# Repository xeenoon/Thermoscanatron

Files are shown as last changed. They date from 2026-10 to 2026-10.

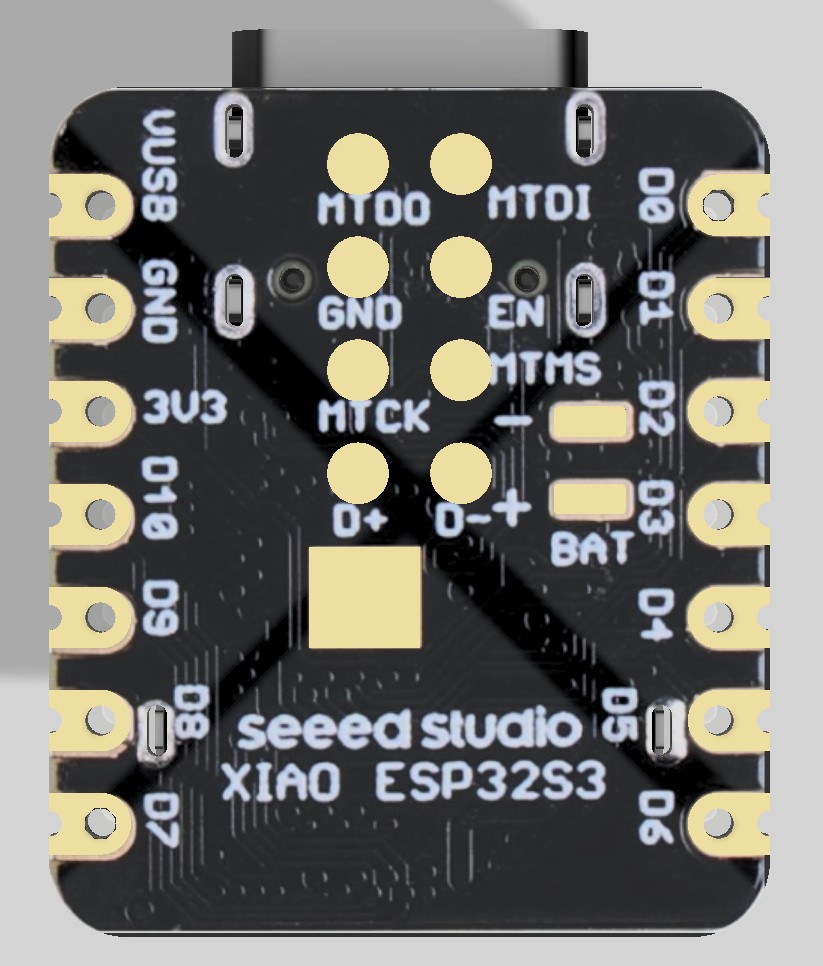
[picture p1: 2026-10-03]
3d/seeed-studio-xiao-esp32s3-3d_model/Bottom View.jpg

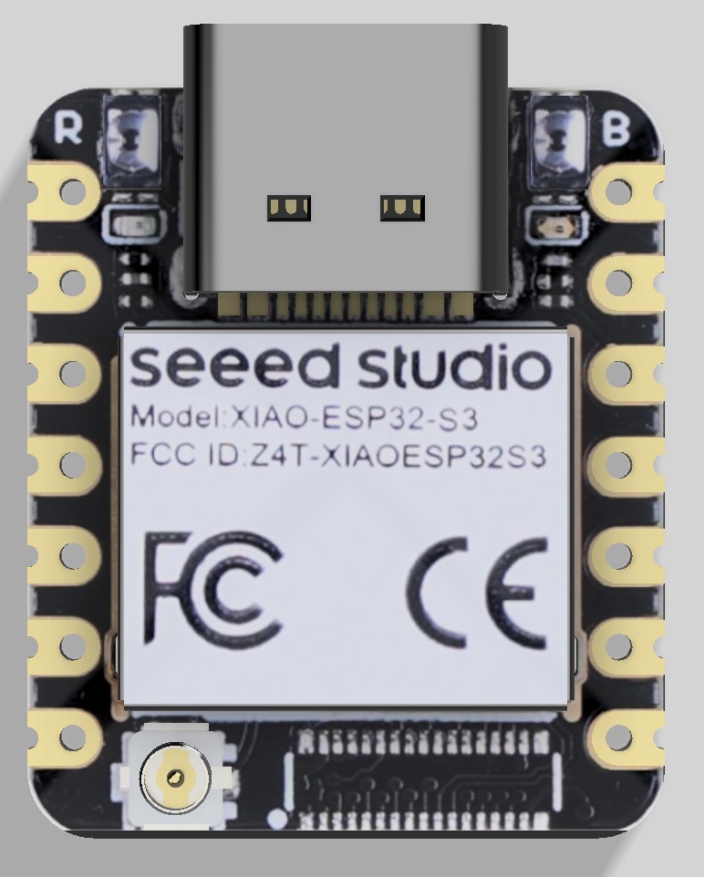
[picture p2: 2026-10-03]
3d/seeed-studio-xiao-esp32s3-3d_model/Top view.jpg

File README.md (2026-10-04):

# Thermoscanatron

## Device components

- MLX90640: $32\times24$ thermal pixels.
- ESP32-S3: factory-calibrated temperature conversion and USB streaming.
- Android app: local ExecuTorch inference, tracking and temperature overlays; the phone also powers the sensor.
- SolidWorks housing: a 3D-printable phone attachment. The revised 100 N simulation gave 1.25 MPa maximum stress and 0.0149 mm displacement.

## Scanner mapping: hand recognition and calibration

HandSegNet uses a MobileNetV3-Small encoder with a U-Net-style decoder and presence head, approximately 1.70 million parameters, at $256\times256$ input resolution.

Our offline labeller combines SegFormer-B2 human parsing with BiRefNet foreground masks and MediaPipe hand landmarks. Landmark-guided cropping removes sleeves; clothing predictions veto false skin regions. These automatically generated masks transfer heavier models' predictions into the compact phone model through supervised pseudo-label training.

The hand estimates the **relative camera pose**. Approximating an open hand as a front-facing plane of area $A_h=130\,\mathrm{cm}^2$, its mask area $a$ gives depth:

```math
Z=f\sqrt{A_h/a},\qquad
P=ZK^{-1}[u,v,1]^T.
```

Here $f$ is focal length in pixels, $K$ is the RGB intrinsic matrix and $(u,v)$ is the hand centroid. For thermal-camera centre $c$ and rotation $R$:

```math
P_T=R^T(P-c),\qquad
R=R_y(\psi)R_x(\theta)R_z(\phi).
```

We fit yaw $\psi$, pitch $\theta$ and roll $\phi$, plus translation, by robust least-squares matching projected hand centroids to thermal warm-blob centroids. The thermal lens uses an equidistant projection: image radius is proportional to ray angle. We then refine pose and lens scale by maximising correlation between projected hand coverage and thermal warmth. Near/far hand motion provides parallax; timestamp alignment compensates sensor delay.

**Training and labelling:** Hand/skin model training totalled **1.84 hours across 13 logged runs**, including validation. The final run used 5,288 training frames, 1,356 validation frames and 2,000 additional negatives. A complete hand-labelling runtime was not retained.

## Solar scanning: recognition, geometry and temperature

PanelNet uses a MobileNetV3-Small encoder and U-Net-style decoder, approximately 1.69 million parameters. The phone uses 192-pixel inputs for fast inference and a 384-pixel recovery model. Outputs include cell masks, gridlines, presence and periodic cell coordinates:

```math
(\sin 2\pi u,\cos 2\pi u,\sin\pi v,\cos\pi v).
```

Column phase repeats every cell; row phase repeats every two rows to encode the panel's alternating diamond pattern. Temporal tracking and gyroscope motion preserve integer cell identities through close-ups.

Our offline labeller combines KLT optical flow, SIFT rematching, gridline/diamond constraints and forward/backward tracking. A hidden Markov model with Viterbi decoding resolves cell numbering across the recording. Its homographies generate dense training targets for the phone network: geometric pseudo-labelling, rather than direct neural teacher/student distillation.

The panel-to-image homography gives its plane pose:

```math
H\sim K[w r_1,\;h r_2,\;t],\qquad n=r_1\times r_2,
```

where $w,h$ are cell dimensions, $r_1,r_2$ are panel axes and $t$ is its origin. A calibrated thermal ray $d$ intersects that plane at:

```math
X=c+\frac{n^T(t-c)}{n^Td}d.
```

Projecting $X-t$ onto the panel axes identifies the cell. Nine rays sample each thermal pixel's footprint; a cell reading accepts only pixels whose entire sampled footprint lies within that cell, excluding boundaries and background.

For accepted thermal pixels $S_i$ in cell $i$ and panel pixels $S_P$:

```math
T_i=\mathrm{median}\{T_p:p\in S_i\},\qquad
\bar T_P=\frac{1}{|S_P|}\sum_{p\in S_P}T_p,\qquad
\Delta T_i=T_i-\bar T_P.
```

We define a **hotspot** as $\Delta T_i>5^\circ\mathrm C$. The implementation flags $|\Delta T_i|>5^\circ\mathrm C$, including cold anomalies. This is our prototype threshold. Readings are apparent surface temperatures with emissivity set to 0.95.

**Training and labelling:** Solar model training totalled **4.23 hours across 22 logged runs**, including validation. One training stage used 8,695 panel frames plus 1,291 negatives. Solar labelling totalled **4.56 logged hours across 74 completed runs on 3–4 October**. These cumulative development totals exclude unlogged work; interrupted labelling runs are additional.

## Demo result

The suspect panel measured 19 V, 4 V below its 23 V baseline; the healthy panel measured 23.7 V, 0.7 V above baseline. Together with the observed hotspots, the voltage deficit supports identifying the demo panel as faulty.

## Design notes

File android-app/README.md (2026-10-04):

# Android apps

Two native Android apps connect on-device computer vision to the USB thermal sensor:

| Module | Application ID | Purpose |
| --- | --- | --- |
| `app/` | `com.euhack.hello` | Hand/skin segmentation, camera calibration and fused thermal viewing |
| `solar/` | `com.euhack.solar` | Solar-cell tracking, temperature mapping and anomaly overlays |

## Setup

Install JDK 17 and the Android SDK. From the repository root, enter this directory and set the paths for your machine:

```bash
cd android-app
export ANDROID_HOME="$HOME/Android/Sdk"
export PATH="$ANDROID_HOME/emulator:$ANDROID_HOME/platform-tools:$PATH"
export JAVA_HOME=/usr/lib/jvm/java-17-openjdk
```

## Run the hand app on a phone

Enable USB debugging and connect the phone, then build and install:

```bash
./gradlew :app:assembleDebug
adb -d install -r app/build/outputs/apk/debug/app-debug.apk
adb -d shell am start -n com.euhack.hello/.DemoActivity
```

The hand app runs live hand/skin segmentation. Its **Options** menu provides:

- **Record camera + thermal**: a silent ≤1080p video to `files/videos/hand_<time>.mp4` (see the [ML workflow](../ML/README.md)) plus a
  session in `files/sessions/<time>/` with every analysed frame (crop, mask, timestamps) and every thermal packet on
  the same clock (`SessionRecorder.kt`). `ML/src/segkit/thermal_calib.py` fits a calibration from a session.
- **Dump NO-HAND frames**: diagnostics to `files/diagnostics/session_<time>/` (see `NoHandLogger.kt`).
- **Stream thermal input**: shows only the MLX90640 thermal image (°C range, max, sensor temperature).
- **Calibrate thermal ↔ camera**: follow the guided near, far, upper-left and lower-left hand positions.
  Keep the open hand visible to both cameras. The result reports yaw, pitch and roll in degrees, translation
  in centimetres and approximate uncertainty. **Use it** saves the result to `files/thermal_calib.json`.
- **Fused thermal view** (after calibrating): displays the cameras' overlapping field of view, with the rest
  black. Visible-image edges guide the enlarged thermal overlay to help associate readings with objects.
  The sensor still measures only 32 × 24 thermal pixels. The status line shows the hand's median temperature
  and the colour scale.

## Thermal camera over USB OTG

Plug the QT Py running the [firmware](../firmware/README.md) into the phone using USB-C or an OTG adapter.
The phone powers the board and reads its calibrated `THM2` stream. Grant Android's USB-access prompt when
connecting the board. Plugging it in can also offer to open the app.

The attachment occupies the phone's USB port. Use wireless debugging (`adb pair` and `adb connect`) during
hardware development.

## Camera calibration

The [Kotlin solver](app/src/main/java/com/euhack/hello/ThermalCalibration.kt) corresponds to the
[Python calibration pipeline](../ML/src/segkit/thermal_calib.py). It fits camera rotation, translation,
thermal lens scale and readout mirroring, subject to physical mounting constraints.

1. **Timing:** estimate thermal latency from the correlation between visible hand area and thermal warm area.
   If the capture cannot establish latency, use the recorded default of 225 ms.
2. **Pose:** estimate hand depth from mask area, assuming an open hand of approximately 130 cm². Match the
   resulting 3D hand centroids to thermal centroids using robust Levenberg–Marquardt and multiple starting poses.
3. **Refinement:** use Nelder–Mead to maximise correlation between predicted hand coverage and thermal warmth,
   refining pose and lens scale.

Follow the guided near/far and corner positions. Depth variation supplies the parallax needed to distinguish
translation from rotation. The app also uses tighter offset constraints for a sensor attached to the phone.

```bash
./gradlew :app:testDebugUnitTest
```

The tests cover synthetic mountings, including 30° yaw, 45° roll and a 20 cm offset. Recorded-session comparisons
require the corresponding local calibration data.

## Solar Cells app

The second app (`com.euhack.solar`, launcher **Solar Cells**) shares the hand app's USB thermal-stream and
calibration code. Build, test and install it with:

```bash
./gradlew :solar:assembleDebug :solar:testDebugUnitTest
adb -d install -r solar/build/outputs/apk/debug/solar-debug.apk
```

Start with a panel corner visible in the guide box, then move closer. The tracker carries the row and column
identities between frames.

A small model (`assets/panelseg_small.pte`, 192 px) runs on every camera frame; the larger model (`panelseg.pte`,
384 px) runs on its own thread and corrects it. Between frames, and through motion blur, the grid follows the
gyroscope. With the thermal camera connected and a saved or bundled calibration, the app displays per-cell
temperatures and flags differences greater than 5 °C from the panel mean. These flags include both hotspots
and cold anomalies.

**Rec** saves model inputs to `files/panel_debug/<time>/` for replay with `segkit-panel-track --crops`.
See the [ML workflow](../ML/README.md#per-cell-temperatures). Models are trained with `segkit-panel-train`.

## Run in an emulator

Use the emulator for the hand app's camera/UI workflow; USB thermal hardware requires a physical phone.
Run these commands after the setup above:

```bash
emulator -list-avds
emulator -avd igcap &
adb -e wait-for-device
while [ "$(adb -e shell getprop sys.boot_completed | tr -d '\r')" != "1" ]; do sleep 1; done

./gradlew :app:assembleDebug
adb -e install -r app/build/outputs/apk/debug/app-debug.apk
adb -e shell am start -n com.euhack.hello/.DemoActivity
```

Replace `igcap` with an AVD shown by `emulator -list-avds`.

## Hand inference performance diagnostics

Normal launches run only the small model with four native threads. The larger model, its input buffer, and its
executor are not created. This avoids background inference blocking tracking and resetting the thread pool.
The larger model remains bundled for optional ADB comparisons. `-S` restarts the process so the native thread
pool and model state start fresh.

```bash
adb -d shell am start -S -W -n com.euhack.hello/.DemoActivity \
  --ez perf_diagnostics true --ez perf_background false --ei perf_threads 4
adb -d logcat -s HandPerf:I HandDemo:I HandTwoTier:I ExecuTorch:I
```

`perf_background` defaults to false. `perf_threads=1..8` sets the requested pool size on each loaded module;
0 or omission uses four threads for the small model (and two for the larger model if explicitly enabled).
`perf_diagnostics` defaults to false. To compare against the previous two-model configuration:

```bash
adb -d shell am start -S -W -n com.euhack.hello/.DemoActivity \
  --ez perf_diagnostics true --ez perf_background true
```

To restore the normal small-model configuration while retaining the detailed logs:

```bash
adb -d shell am start -S -W -n com.euhack.hello/.DemoActivity --ez perf_diagnostics true
```

`HandPerf` reports normalisation, input tensor construction, native `forward`, output extraction, and
background input preparation in microseconds. `callerCpuUs` counts only the calling thread's CPU time,
not the native worker threads; compare it with wall time and the background-off control, not with total CPU
usage. `bigBusyAtStart` says whether a background job was outstanding when the frame began. Every 30 frames
it also logs camera dimensions, analysis and sensor timestamp gaps, active recording/fusion modes, and UI
queue delay (not display presentation latency). Existing `HandDemo` stage times remain in milliseconds.

Measured before changing the default on the Galaxy A35, 2026-10-03, with the bundled skin models, live 640×480 camera input, and
recording, dumping and fusion off. Each mode ran for 15 seconds after launch, excluding its first 30
analysed frames. That diagnostic build loaded both models even when background inference was off; the current
build skips loading the disabled larger model. FPS below is measured from consecutive analysis log timestamps;
it is not 1000/frame time.

| Configuration | Samples | Median native small call | Median whole analysis | Observed FPS |
| --- | ---: | ---: | ---: | ---: |
| Background on, shared pool 2 | 71 | 114.65 ms | 138 ms | 6.47 |
| Background off, shared pool 2 | 348 | 30.92 ms | 37 ms | 26.49 |
| Background off, shared pool 4 | 403 | 20.91 ms | 27 ms | 29.99 |
| Background on, shared pool 4 | 121 | 77.86 ms | 94 ms | 10.25 |
| Background on, shared pool 2, repeat | 82 | 115.01 ms | 132 ms | 7.55 |

The background model blocks the foreground inference path. In the repeat run, the small call takes 115 ms
of wall time but only 31.58 ms of caller CPU, versus 30.92 ms wall/30.56 ms caller CPU without background
inference. Input copying is about 0.6–1.4 ms and output extraction about 0.2 ms. The small model reached approximately 30 FPS with four threads in this short test. These short runs do not establish sustained thermal
performance or accuracy with background checking disabled.

Two native-runtime details explain the behaviour:

- ExecuTorch 1.5.1's Android JNI [resets a process-wide thread pool on module construction](https://github.com/pytorch/executorch/blob/v1.5.1/extension/android/jni/jni_layer.cpp#L320-L339).
  Loading the larger model last changes both models to two threads. The device logs explicitly show resets to
  four and then two; the requested counts are not independent budgets.
- Its [Android build enables shared XNNPACK workspace](https://github.com/pytorch/executorch/blob/v1.5.1/tools/cmake/preset/android.cmake#L19),
  and [delegate execution holds the workspace lock](https://github.com/pytorch/executorch/blob/v1.5.1/backends/xnnpack/runtime/XNNPACKBackend.cpp#L158-L189).
  Moving the larger model to a low-priority Java thread does not give it independent native resources.

The chosen default is small-model tracking with four threads; the larger model's presence veto/confirmation is
disabled. Keeping background checking while fixing the blocking would require isolating its native execution
resources (for example, a separate Android process), then repeating the handset measurements. Merely
increasing the shared pool to four threads still gave about 10 FPS in the comparison.

After installing this default, a normal launch with no extras measured **29.94 FPS** over 545 frames after
discarding the first 30 frames (20-second capture). Median reported small inference, including input tensor
construction, was 22 ms; whole analysis was 25 ms. Logs confirmed one pool initialisation at four threads,
no background inference, and no model or crash errors.

## References

- F. Hong, J. Song, H. Meng, R. Wang, F. Fang, G. Zhang, "A novel framework on intelligent detection for module
  defects of PV plant combining the visible and infrared images", *Solar Energy* 236 (2022) 406–416,
  [doi:10.1016/j.solener.2022.03.018](https://doi.org/10.1016/j.solener.2022.03.018). The architecture this
  follows: the visible camera supplies geometry/segmentation, the low-resolution IR camera the temperatures,
  joined by a calibrated mapping.
- K. He, J. Sun, X. Tang, "Guided Image Filtering", *IEEE TPAMI* 35(6) (2013) 1397–1409,
  [doi:10.1109/TPAMI.2012.213](https://doi.org/10.1109/TPAMI.2012.213). Used to upsample the 32×24 temperatures
  along the camera's edges (`FusionRenderer.kt`).
- J. Kopf, M. F. Cohen, D. Lischinski, M. Uyttendaele, "Joint Bilateral Upsampling", *ACM TOG* 26(3) (2007) 96,
  [doi:10.1145/1276377.1276497](https://doi.org/10.1145/1276377.1276497). The same guided-upsampling idea; the guided
  filter is used because it runs in O(pixels).

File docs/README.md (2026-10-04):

# Hardware documentation

Local reference manuals for the thermal attachment's microcontroller and infrared sensor. Use these documents
for wiring, pin assignments, electrical limits and sensor communication. Build instructions are in the
[firmware README](../firmware/README.md); phone integration is covered by the [Android README](../android-app/README.md).

## QT Py ESP32-S3 (ADA5700)

- [Adafruit product guide](qt-py-esp32-s3/adafruit-qt-py-esp32-s3-guide.pdf) — pinouts, power, peripherals, schematic, and fabrication drawing
- [Adafruit pinout](qt-py-esp32-s3/adafruit-qt-py-esp32-s3-pinout.pdf) — one-page board pin map
- [ESP32-S3 datasheet](qt-py-esp32-s3/esp32-s3-datasheet.pdf) — chip specifications and GPIO functions
- [ESP32-S3 technical reference manual](qt-py-esp32-s3/esp32-s3-technical-reference-manual.pdf) — peripheral and register reference

## MLX90640 thermal camera (ADA4407)

The project uses the MLX90640-BAB variant, with a nominal 55° × 35° field of view.

- [Adafruit product guide](mlx90640/adafruit-mlx90640-breakout-guide.pdf) — breakout pinouts, wiring, schematic, and fabrication drawing
- [Melexis MLX90640 datasheet](mlx90640/mlx90640-datasheet.pdf) — sensor specifications, I2C protocol, registers, and EEPROM layout
- [Melexis MLX90640 driver guide](mlx90640/mlx90640-driver.pdf) — reference-driver API and measurement flow

## Upstream sources

- [Adafruit QT Py ESP32-S3 guide](https://learn.adafruit.com/adafruit-qt-py-esp32-s3)
- [QT Py ESP32-S3 PCB files](https://github.com/adafruit/Adafruit-QT-Py-ESP32-S3-PCB)
- [Espressif technical documentation](https://www.espressif.com/en/support/documents/technical-documents)
- [Adafruit MLX90640 guide](https://learn.adafruit.com/adafruit-mlx90640-ir-thermal-camera)
- [Melexis MLX90640 datasheet](https://www.melexis.com/en/documents/documentation/datasheets/datasheet-mlx90640)
- [Melexis reference driver](https://github.com/melexis/mlx90640-library)

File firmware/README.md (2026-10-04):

# Thermal-sensor firmware

ESP32-S3 firmware for the QT Py and MLX90640 thermal camera. It reads the sensor, converts measurements to temperatures and streams binary packets to the [Android apps](../android-app/README.md) or [desktop viewer](../test_thermal_stream/README.md).

The project uses ESP-IDF v5.5.5, its FreeRTOS port and Espressif's `led_strip` component. Downloaded dependencies and build output are excluded from Git.

## Build and flash

From the repository root:

```bash
cd firmware
./tools/bootstrap.sh
source dependencies/esp-idf/export.sh
idf.py build
idf.py flash monitor
```

The bootstrap script downloads the pinned ESP-IDF release and installs its ESP32-S3 tools. If multiple serial devices are connected, select the board explicitly:

```bash
idf.py -p /dev/ttyACM0 flash monitor
```

Hardware guides and pinouts are indexed in [docs/README.md](../docs/README.md).

## Temperature conversion

The MLX90640 runs in chess mode at eight subpages per second. Each subpage is converted on the board using the Melexis reference driver in `components/mlx90640_melexis` (Apache-2.0) and the sensor's EEPROM calibration.

Conversion uses emissivity **0.95** and reflected temperature **ambient − 8 °C**. Bad pixels are interpolated. These settings affect the reported apparent object temperatures.

## USB packet format

Each subpage produces one **THM2** packet over USB-Serial-JTAG. Packets are **1,566 bytes**, with multibyte fields encoded little-endian.

| Byte offset | Bytes | Field |
| ---: | ---: | --- |
| 0 | 4 | Magic: `THM2` |
| 4 | 1 | Protocol version: 2 |
| 5 | 1 | Subpage: 0 or 1 |
| 6 | 2 | Header length: 28 bytes |
| 8 | 4 | Sequence number |
| 12 | 8 | `esp_timer` timestamp in microseconds |
| 20 | 2 | Payload length: 769 words |
| 22 | 1 | Image width: 32 |
| 23 | 1 | Image height: 24 |
| 24 | 4 | CRC32 of the payload |
| 28 | 1,536 | 768 signed 16-bit pixel temperatures, row-major, in hundredths of a degree Celsius |
| 1,564 | 2 | Signed 16-bit sensor ambient temperature, in hundredths of a degree Celsius |

Each packet contains a merged image: the newly read subpage and the other half from the preceding subpage. The two halves therefore represent successive sensor reads, not a simultaneous full-frame exposure.

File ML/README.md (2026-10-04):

# Machine learning and calibration

Python tools for dataset labelling, model training, camera calibration and solar-cell tracking. Models can run in the browser demo or be exported to the [Android apps](../android-app/README.md) with ExecuTorch.

## Setup

Run the examples below from this directory. Use Python 3.12 and `uv`; video extraction also requires `ffmpeg`.

```bash
cd ML
uv sync --extra cpu
uv run --extra cpu segkit-hello-world
uv run --extra cpu pytest
```

For an NVIDIA GPU, replace `--extra cpu` with `--extra cu130` in both setup and run commands. Keep the same extra on every `uv run` invocation so dependency resolution retains the intended PyTorch and ONNX Runtime builds.

Dependencies and command entry points are defined in [pyproject.toml](pyproject.toml).

## Browser webcam demo

The Gradio/FastRTC server processes camera frames supplied by a laptop or phone browser over WebRTC. Select either the stateful solar-cell tracker or the hand-segmentation model.

```bash
uv sync --extra cpu --extra web
uv run --extra cpu --extra web segkit-panel-web
```

Open <http://127.0.0.1:7860>. The demo prefers training checkpoints and falls back to models bundled with the Android apps. Override the models with `--model` / `SEGKIT_PANEL_MODEL` and `--hand-model` / `SEGKIT_HAND_MODEL`.

For a Hugging Face Space, configure an `HF_TOKEN` Space secret for FastRTC's TURN credentials. The demo processes frames in memory without recording them.

## Hand dataset

Record a video in the hand app using **Options → Record camera + thermal**, then copy the videos from the phone:

```bash
adb pull /sdcard/Android/data/com.euhack.hello/files/videos data/
uv run --extra cpu segkit-extract data/videos --out data/captures --fps 3
uv run --extra cpu segkit-label data/captures --out data/hands_v1
uv run --extra cpu segkit-validate data/hands_v1
```

Frame extraction selects the sharpest image in each one-third-second window. Labelling is resumable; use `--limit 5` for a small trial. The default foreground model is `birefnet-general-lite`; `--model isnet-general-use` selects an alternative.

The dataset contains `images/`, `masks/`, `overlays/` and `index.csv`. Inspect the review sheets and list rejected frame stems in `exclude.txt` before training. The separate [skin labeller](src/segkit/label_skin.py) combines human parsing and hand outlines for skin-model datasets.

## Hand evaluation

Place full-resolution frames in `data/eval/` and annotate them with LabelMe:

- **hand:** the hand outline, cut across the wrist.
- **hole:** background enclosed by the hand.
- **ignore:** the wrist-cut band, excluded from scoring.

```bash
uvx --python 3.12 labelme data/eval --output data/eval --labels hand,hole,ignore
uv run --extra cpu segkit-eval check data/eval
uv run --extra cpu segkit-eval score data/eval runs/predictions --csv runs/scores.csv
```

Replace `runs/predictions` with the prediction directory. Each prediction must be a full-resolution PNG named after its source image, with nonzero pixels marking the hand. Check the overlays in `runs/eval_check/` before scoring. The evaluation target is a 95th-percentile boundary error of at most two pixels; this is a target, not a reported result.

## Thermal-camera calibration

Record **Options → Record camera + thermal**, then copy the matching `files/sessions/SESSION_ID/` directory into `data/thermal_sessions/`. Replace `SESSION_ID` in the example:

```bash
uv run --extra cpu python -m segkit.thermal_calib data/thermal_sessions/SESSION_ID --t-ranges 0-55,60-70
uv run --extra cpu pytest tests/test_thermal_calib.py
```

The time ranges select usable seconds from the recording. Results are written to `runs/thermal_calib/thermal_calib.json` and `check.jpg`, including camera pose, lens scale, latency, uncertainty estimates and a projected-hand preview.

The [Python implementation](src/segkit/thermal_calib.py) documents the model and solver. The phone uses the corresponding [Kotlin implementation](../android-app/app/src/main/java/com/euhack/hello/ThermalCalibration.kt). Move the hand nearer and farther during capture so parallax can distinguish camera offset from rotation.

## Solar-cell labelling and training

The default [panel profile](src/segkit/panel/spec.py) describes four columns and nine rows of half-cut cells, including the alternating diamond pattern and gridline width. The labeller accepts `--spec profile.json` for another layout; verify its labels and physical dimensions before using that profile for temperature mapping.

Capture a panel recording with the hand app, moving from a full-panel view into close-ups and back. Set `panel_session_id` to the recording's timestamp:

```bash
panel_session_id=SESSION_ID
panel_session="data/panel/$panel_session_id"
adb pull "/sdcard/Android/data/com.euhack.hello/files/sessions/$panel_session_id" data/panel/
adb pull "/sdcard/Android/data/com.euhack.hello/files/videos/hand_$panel_session_id.mp4" "$panel_session/video.mp4"
mkdir -p "$panel_session/frames"
ffmpeg -i "$panel_session/video.mp4" -q:v 2 "$panel_session/frames/%05d.jpg"
```

Create `anchors.json` in the session directory with at least four panel correspondences for selected wide views. Diamond intersections are useful landmarks; see `segkit-panel-label --help` for the format.

```bash
uv run --extra cpu segkit-panel-label "$panel_session"
uv run --extra cpu segkit-panel-train "$panel_session" --negatives data/panel/negatives.txt --out runs/panel_v1
uv run --extra cpu segkit-panel-track "$panel_session" --model runs/panel_v1/panelseg.pte --video runs/panel_v1/track.mp4
uv run --extra cpu segkit-panel-track "$panel_session" --oracle
```

Review `panel_labels.npz` and `review/sheet_NN.jpg` before training. Correct anchors or add rejected intervals, then rerun the labeller. The negative-image list must contain suitable panel-free examples. Oracle mode evaluates the tracker using label targets instead of model predictions.

PanelNet predicts cell area, gridlines and periodic within-cell coordinates. The tracker maintains integer row and column identities over time; a close-up of a repeating cell pattern cannot establish its identity by appearance alone.

## Per-cell temperatures

Use the saved calibration with either labelled geometry or tracker output:

```bash
uv run --extra cpu segkit-panel-thermal "$panel_session" --calib runs/thermal_calib/thermal_calib.json
uv run --extra cpu segkit-panel-thermal "$panel_session" --calib runs/thermal_calib/thermal_calib.json --source tracker
```

Outputs include `thermal_cells[_tracker].csv` and `thermal_summary[_tracker].json` / `.jpg`: cell temperatures, differences from the panel mean and anomaly flags.

A hotspot is more than 5 °C above the panel mean. The implementation flags differences greater than 5 °C in either direction, so its flags also include cold anomalies. Thermal-pixel footprints are projected onto the panel plane; only footprints entirely within one cell contribute to that cell's reading. This reduces contamination from boundaries and background.

The [Solar Cells app](../android-app/README.md#solar-cells-app) also records analysis crops for `segkit-panel-track --crops` replay.

## References

- F. Hong, J. Song, H. Meng, R. Wang, F. Fang, G. Zhang, "A novel framework on intelligent detection for module
  defects of PV plant combining the visible and infrared images", *Solar Energy* 236 (2022) 406–416,
  [doi:10.1016/j.solener.2022.03.018](https://doi.org/10.1016/j.solener.2022.03.018). The architecture this
  follows: the visible camera supplies geometry/segmentation, the low-resolution IR camera the temperatures,
  joined by a calibrated mapping.
- K. He, J. Sun, X. Tang, "Guided Image Filtering", *IEEE TPAMI* 35(6) (2013) 1397–1409,
  [doi:10.1109/TPAMI.2012.213](https://doi.org/10.1109/TPAMI.2012.213). Used to upsample the 32×24 temperatures
  along the camera's edges (`android-app/.../FusionRenderer.kt`).
- J. Kopf, M. F. Cohen, D. Lischinski, M. Uyttendaele, "Joint Bilateral Upsampling", *ACM TOG* 26(3) (2007) 96,
  [doi:10.1145/1276377.1276497](https://doi.org/10.1145/1276377.1276497). The same guided-upsampling idea; the guided
  filter is used because it runs in O(pixels).

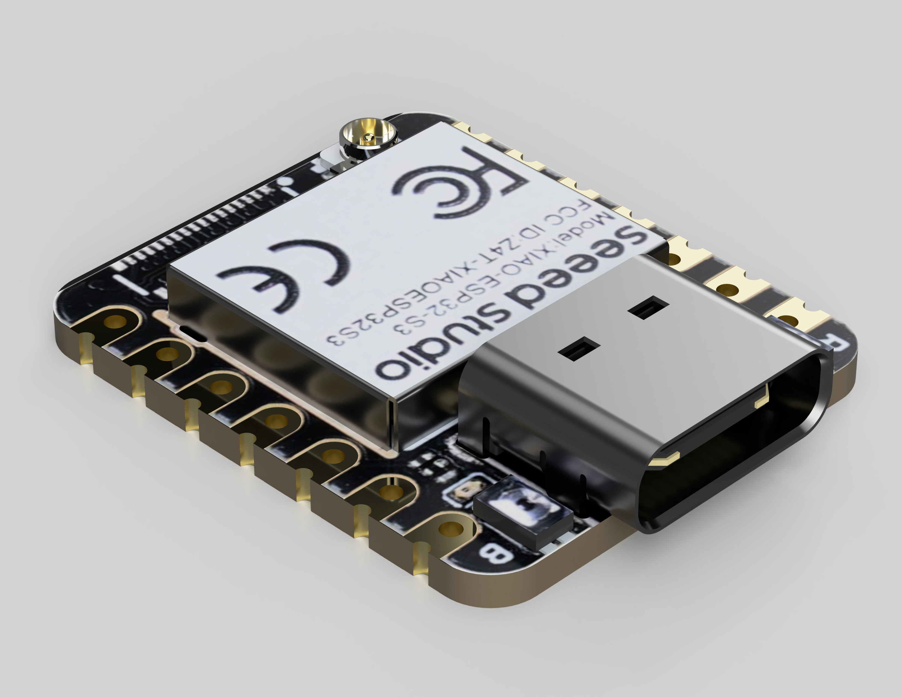
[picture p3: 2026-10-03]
3d/seeed-studio-xiao-esp32s3-3d_model/XIAO-ESP32S3.png

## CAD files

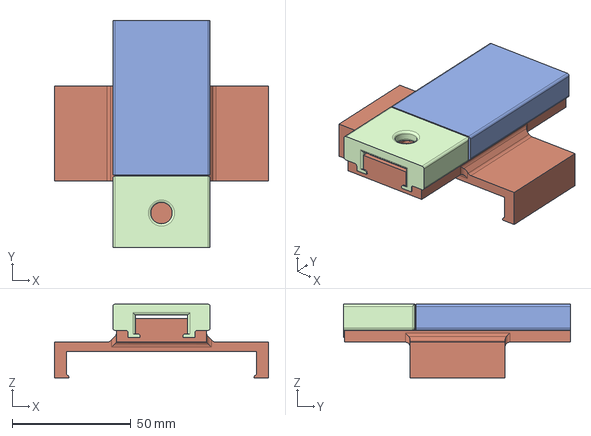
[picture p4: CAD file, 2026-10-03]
3d/HACKATHON_ASSEMBLY2.step
90.0 x 95.5 x 31.0 mm

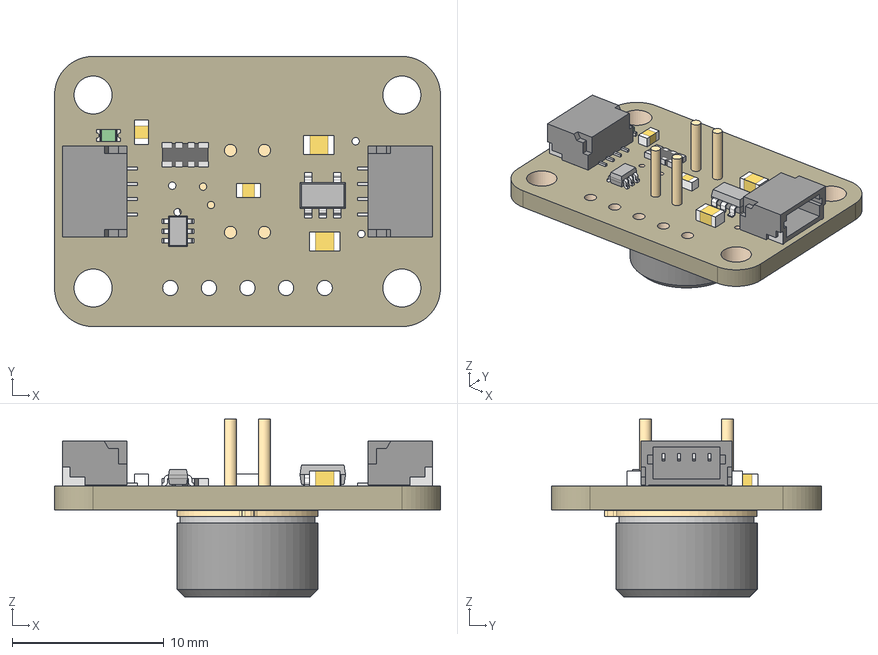
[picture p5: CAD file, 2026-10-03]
3d/hackathon_files/New folder/4469 MLX90640 Stemma.step
25.4 x 17.8 x 11.7 mm
Board
10uF x 2
AP2112K-3.3
10K x 2
4.7K
BSS138
STEMMA_I2C_QT x 2
GREEN
MLX90640

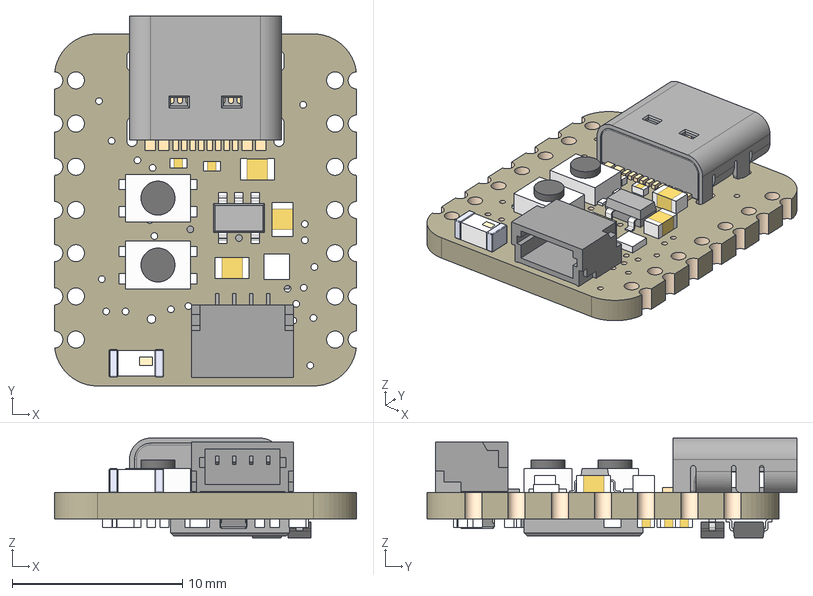
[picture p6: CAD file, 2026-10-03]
3d/hackathon_files/USBC/5426 QT Py ESP32-S3.step
17.8 x 21.8 x 5.87 mm
Board
22uF x 3
BOOT0 x 2
1uF x 23
USB TYPE C
STEMMA_I2C_QTSKINNY
AP2112K-3.3
WS2812B_SK6805_1515
NSR0320 x 2
0 ohm
40MHz
2.4 GHz Antenna
ESP32-S3QFN54
TPB1,27 x 2

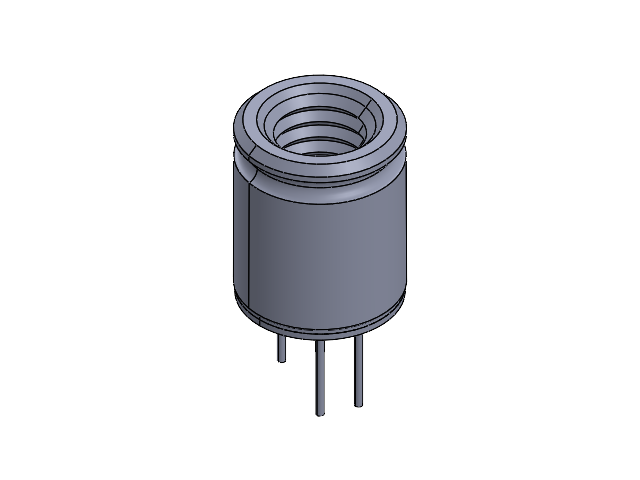
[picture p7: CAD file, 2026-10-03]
3d/3D Models MLX90640 - Melexis (2)/MLX90640/thermal_cam.SLDASM
90640-GLASS_ANY.stp x 3
90640PIN_ANY.stp x 3
90640-BASE_ANY.stp
90640-BRAZED-PIN_ANY.stp
90640-60X15-APPERTURE_ANY.stp
90640-LENSE_ANY.stp
90640-CAP_ANY.stp

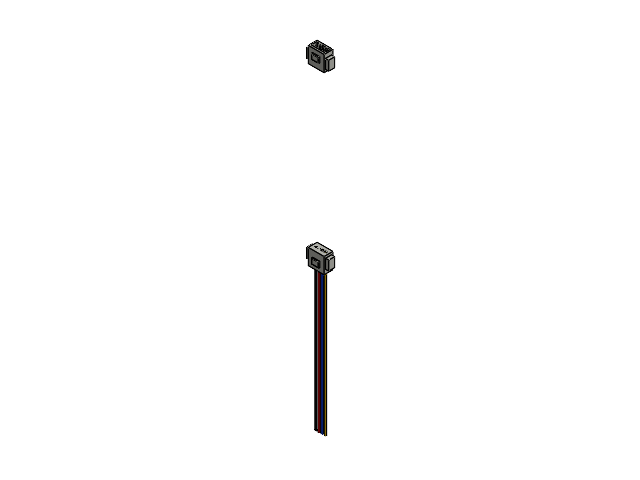
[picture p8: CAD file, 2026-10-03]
3d/cable.SLDASM
plug_A_housing.step x 2
plug_A_contact_1.step x 2
plug_A_contact_2.step x 2
plug_A_contact_3.step x 2
plug_A_contact_4.step x 2
wire_1.step
wire_2.step
wire_3.step
wire_4.step

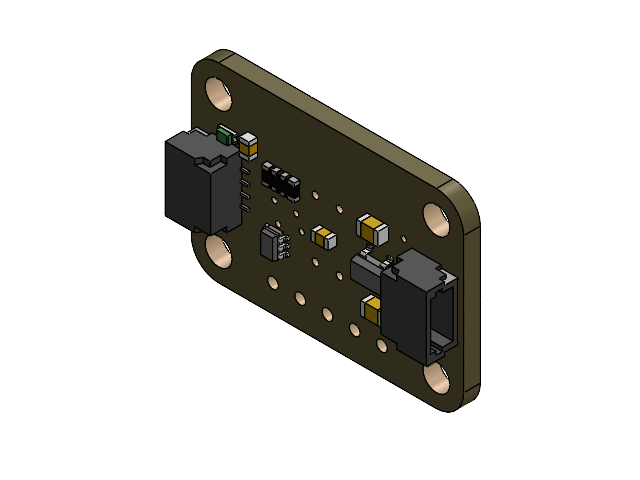
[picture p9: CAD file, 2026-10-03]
3d/hackathon_files/4469 MLX90640 Stemma (1).SLDASM
Board.step
10uF.step x 2
AP2112K-3.3.step
10K.step x 2
4.7K.step
BSS138.step
STEMMA_I2C_QT.step x 2
GREEN.step

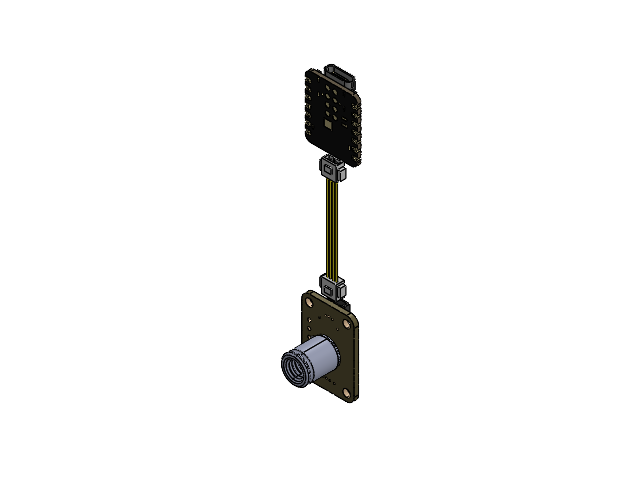
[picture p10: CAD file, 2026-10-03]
3d/eletronics_assemebly.SLDASM
BOSS-EXTRUDE14_8_.step
BOSS-EXTRUDE7_4_.step
BOSS-EXTRUDE7_3_.step
BOSS-EXTRUDE14_4_.step
BOSS-EXTRUDE14_2_.step
BOSS-EXTRUDE14_11_.step
BOSS-EXTRUDE7_7_.step
BOSS-EXTRUDE14_9_.step
BOSS-EXTRUDE14_3_.step
BOSS-EXTRUDE14_7_.step
MIRROR2.step
BOSS-EXTRUDE14_5_.step
BOSS-EXTRUDE14_12_.step
BOSS-EXTRUDE7_8_.step
BOSS-EXTRUDE7_1_.step
BOSS-EXTRUDE14_10_.step
BOSS-EXTRUDE7_9_.step
BOSS-EXTRUDE14_6_.step
CHAMFER9.step
BOSS-EXTRUDE14_1_.step
BOSS-EXTRUDE7_6_.step
BOSS-EXTRUDE7_2_.step
CUT-EXTRUDE5.step
BOSS-EXTRUDE7_5_.step
Body.step x 2
Pins.step x 2
Shield.step
U.FL-R-SMT-1_10_ v1.step
Seeed Studio XIAO-ESP32-S3 (Sense)-0.step
Board.step
10uF.step x 2
AP2112K-3.3.step
10K.step x 2
4.7K.step
BSS138.step
STEMMA_I2C_QT.step x 2
GREEN.step
90640-GLASS_ANY.stp x 3
90640PIN_ANY.stp x 3
90640-BASE_ANY.stp
90640-BRAZED-PIN_ANY.stp
90640-60X15-APPERTURE_ANY.stp
90640-LENSE_ANY.stp
90640-CAP_ANY.stp

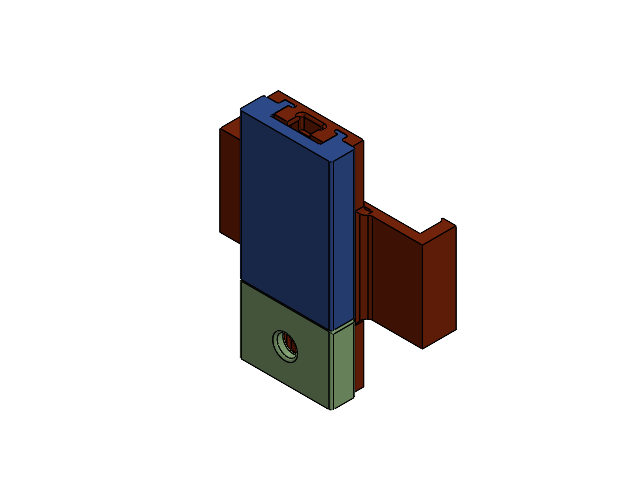
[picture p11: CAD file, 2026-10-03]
3d/HACKATHON_+studies.SLDASM
Part 1.step
Part 1-0.step
Part 2.step

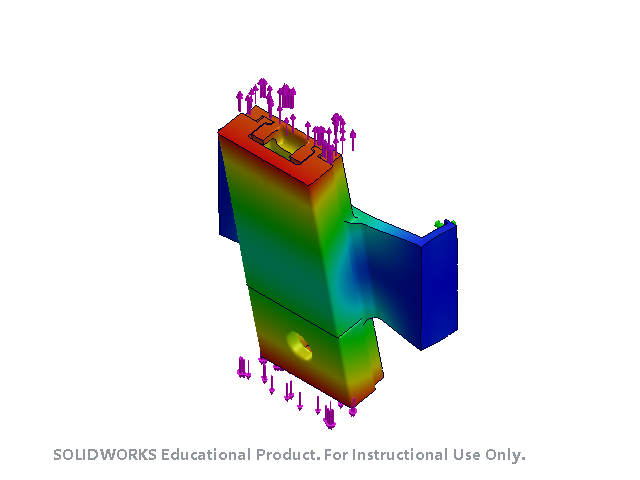
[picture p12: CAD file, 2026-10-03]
3d/HACKATHON_ASSEMBLY_v4_+Studies.SLDASM
Part 1.step
Part 1-0.step
Part 2.step

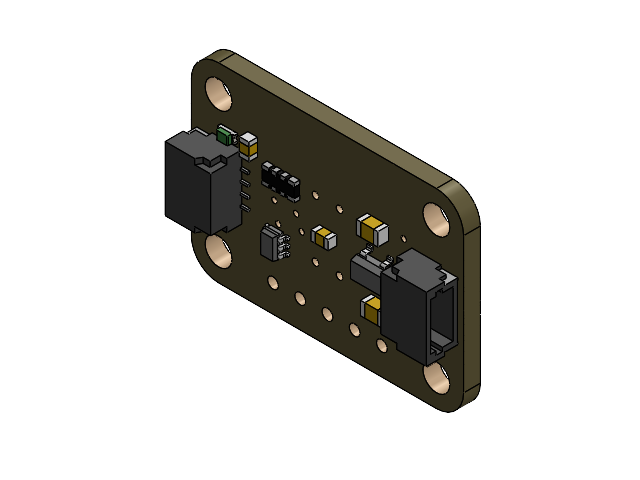
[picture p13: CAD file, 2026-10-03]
3d/thermal camera.SLDASM
Board.step
10uF.step x 2
AP2112K-3.3.step
10K.step x 2
4.7K.step
BSS138.step
STEMMA_I2C_QT.step x 2
GREEN.step

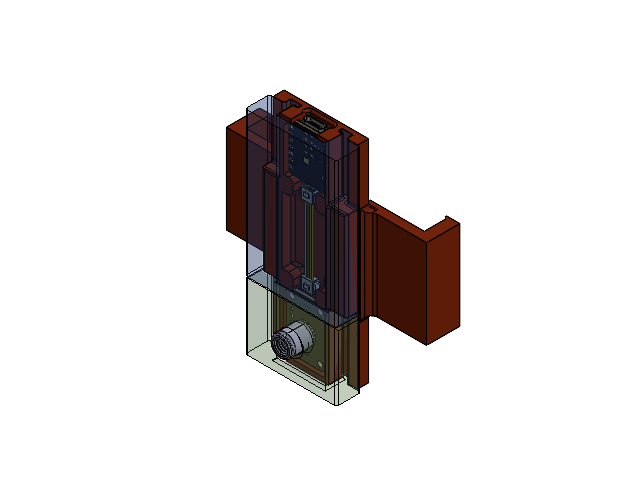
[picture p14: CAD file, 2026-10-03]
3d/HACKATHON_ASSEMBLY_V3+eletronics.SLDASM
BOSS-EXTRUDE14_8_.step
BOSS-EXTRUDE7_4_.step
BOSS-EXTRUDE7_3_.step
BOSS-EXTRUDE14_4_.step
BOSS-EXTRUDE14_2_.step
BOSS-EXTRUDE14_11_.step
BOSS-EXTRUDE7_7_.step
BOSS-EXTRUDE14_9_.step
BOSS-EXTRUDE14_3_.step
BOSS-EXTRUDE14_7_.step
MIRROR2.step
BOSS-EXTRUDE14_5_.step
BOSS-EXTRUDE14_12_.step
BOSS-EXTRUDE7_8_.step
BOSS-EXTRUDE7_1_.step
BOSS-EXTRUDE14_10_.step
BOSS-EXTRUDE7_9_.step
BOSS-EXTRUDE14_6_.step
CHAMFER9.step
BOSS-EXTRUDE14_1_.step
BOSS-EXTRUDE7_6_.step
BOSS-EXTRUDE7_2_.step
CUT-EXTRUDE5.step
BOSS-EXTRUDE7_5_.step
Body.step x 2
Pins.step x 2
Shield.step
U.FL-R-SMT-1_10_ v1.step
Seeed Studio XIAO-ESP32-S3 (Sense)-0.step
Board.step
10uF.step x 2
AP2112K-3.3.step
10K.step x 2
4.7K.step
BSS138.step
STEMMA_I2C_QT.step x 2
GREEN.step
90640-GLASS_ANY.stp x 3
90640PIN_ANY.stp x 3
90640-BASE_ANY.stp
90640-BRAZED-PIN_ANY.stp
90640-60X15-APPERTURE_ANY.stp
90640-LENSE_ANY.stp
90640-CAP_ANY.stp

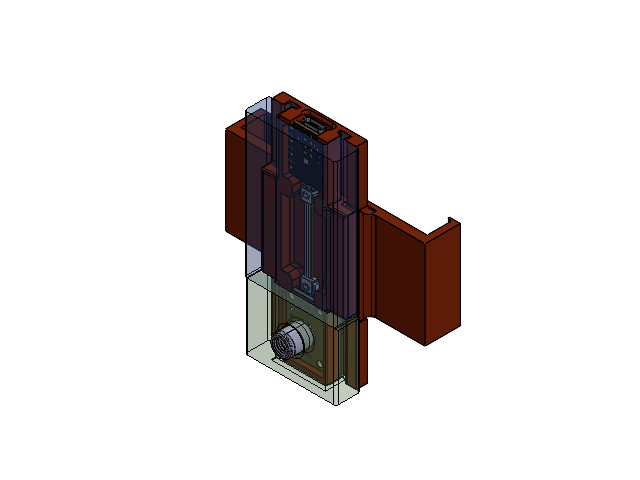
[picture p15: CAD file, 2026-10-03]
3d/V4_HACKATHON_assembly.SLDASM
Part 1.step
Part 1-0.step
Part 2.step
BOSS-EXTRUDE14_8_.step
BOSS-EXTRUDE7_4_.step
BOSS-EXTRUDE7_3_.step
BOSS-EXTRUDE14_4_.step
BOSS-EXTRUDE14_2_.step
BOSS-EXTRUDE14_11_.step
BOSS-EXTRUDE7_7_.step
BOSS-EXTRUDE14_9_.step
BOSS-EXTRUDE14_3_.step
BOSS-EXTRUDE14_7_.step
MIRROR2.step
BOSS-EXTRUDE14_5_.step
BOSS-EXTRUDE14_12_.step
BOSS-EXTRUDE7_8_.step
BOSS-EXTRUDE7_1_.step
BOSS-EXTRUDE14_10_.step
BOSS-EXTRUDE7_9_.step
BOSS-EXTRUDE14_6_.step
CHAMFER9.step
BOSS-EXTRUDE14_1_.step
BOSS-EXTRUDE7_6_.step
BOSS-EXTRUDE7_2_.step
CUT-EXTRUDE5.step
BOSS-EXTRUDE7_5_.step
Body.step x 2
Pins.step x 2
Shield.step
U.FL-R-SMT-1_10_ v1.step
Seeed Studio XIAO-ESP32-S3 (Sense)-0.step
Board.step
10uF.step x 2
AP2112K-3.3.step
10K.step x 2
4.7K.step
BSS138.step
STEMMA_I2C_QT.step x 2
GREEN.step
90640-GLASS_ANY.stp x 3
90640PIN_ANY.stp x 3
90640-BASE_ANY.stp
90640-BRAZED-PIN_ANY.stp
90640-60X15-APPERTURE_ANY.stp
90640-LENSE_ANY.stp
90640-CAP_ANY.stp

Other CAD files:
3d/hackathon_files/USBC/USBC_Attachment.SLDASM
3d/hackathon_files/New folder/thermal_camera_2.SLDASM
3d/hackathon_files/New folder/thermal camera.SLDASM
3d/HACKATHON_ASSEMBLY_V3.step.SLDASM
3d/HACKATHON_ASSEMBLY_V3.step
3d/HACKATHON_ASSEMBLY.step
3d/3D Models MLX90640 - Melexis (2)/MLX90640/MLX90640_41_FOV_55_asm.stp
3d/Adafruit_5700_QT_Py_S3_keepout_preview (1).stl
3d/Adafruit_5700_QT_Py_S3_keepout_preview.stl
3d/HACKATHON_ASSEMBLY (1).step
3d/HACKATHON_ASSEMBLY_v3 (1).step
3d/INSERT_DIRECTLY_JST_SH_4pin_30mm_WIRES.SLDASM
3d/INSERT_DIRECTLY_JST_SH_4pin_30mm_WIRES.step
3d/INSERT_DIRECTLY_JST_SH_4pin_CONNECTOR_PAIR.SLDASM
3d/INSERT_DIRECTLY_JST_SH_4pin_CONNECTOR_PAIR.step
3d/JST_SH_4pin_STEMMA_QT_50mm_cable.step
3d/JST_SH_4pin_STEMMA_QT_50mm_cable_robust.step
3d/MLX90640_41_FOV_110_asm.stp
3d/MLX90640_41_FOV_55_asm.SLDASM
3d/MLX90640_41_FOV_55_asm.stp
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

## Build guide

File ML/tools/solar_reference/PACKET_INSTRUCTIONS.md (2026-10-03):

# Ordered solar-panel tracking task

read every image in this folder in the order that they are named and place the tracking data as defined by format.json

**view each image seperately and analyse. Prove your work passes before handing back**

## Your input and output

Your task is ONLY the 118 original images in the root `images/` folder, in ascending filename order, matching the root `manifest.json`. This packet is one consecutive section of the latest recording. Preserve every frame and its source identity, including no-panel, uncertain, or lost frames. Do not reorder, silently skip, or add frames.

`format.json` defines the output format. `tracking_template.json` is an EMPTY structure with your frame identities populated. There is intentionally NO root `tracking.json` answer. Create it from your images.

Return **only your newly created `tracking.json`** matching `format.json`. Do **NOT** draw labels, generate overlays, modify images, or return annotated images. Keep the manifest's sequence and recording IDs unchanged.

## Separate context and solved example

- `context/` contains full-panel views selected from an individually verified set for this packet's start and end. Their actual source frame numbers, signed offsets and temporal relationship are in `context/manifest.json`. They are NOT the actual first/last task frames and are NOT additional frames to label. A context image may be temporally distant, come from before OR after the task, and be reused in several packets.
- `example/` is a separate solved wide-to-close-up sequence. Read its `README.md`, original images, `tracking.json`, and `visual_key/` to understand coordinates and stable grid identity. That JSON answers the EXAMPLE ONLY. Never submit it as your packet's output. Always match `frame_id` and `image_file` to the root manifest.
- The example's solution is deliberately sparse: reviewed internal white-diamond centers, no extrapolated full grid. Its visual key illustrates these points, not an extra task sequence. Uncertain positions are withheld. The example is a reviewed annotation, not a calibrated guarantee of zero pixel error.
- Context and example are aids for offline labeling. Future context must not be used as if it were causal input when evaluating an online inference tracker. Recordings may contain the example frames in their ordinary chronological section as well; they remain task frames when listed in the root manifest.

## Physical grid and pixel coordinates

- Panel: 4 cell columns × 9 cell rows. Boundary intersections use `u=0..4` left-to-right and `v=0..9` top-to-bottom on the physical panel. The origin is the upper-left of the cell area, inside the metal frame.
- White diamonds occur at internal columns `u=1,2,3` and rows `v=2,4,6,8`. Thin metallic busbars inside cells are NOT column boundaries. Odd row boundaries have ordinary gaps.
- Coordinates use ORIGINAL 1080×1440 pixels: x right, y down, `(0,0)` at the upper-left image corner. Convert cropped/resized coordinates back before returning them.
- `panel0:u1:v2` must always identify the same physical junction. As the camera zooms in, do NOT renumber the remaining visible cells or points from zero. Preserve physical identity even as panel edges leave view. Cell names `Ccolumn Rrow`, when shown in the example, are zero-based cells, not boundary intersections.
- Chamfer tips are not intersections of extended cell edges. Extrapolated corners are inferred, not directly observed.

## Required individual review

1. Open EACH original task image separately, in order. Inspect at native resolution or using unannotated detail crops where needed. A contact sheet, existing predictions, or an inferred plane do not substitute for seeing that image. If an image cannot be accessed, state the limitation; do not claim inspection.
2. Select confidently visible grid junctions, preferably diamond centers, independently from each image. Use `method: "model_observation"` for directly selected points. Track physical identities through the sequence. Do not force a complete 50-point grid or omit clear junctions merely to avoid checking them.
3. Use `"inferred"` or `"tracked_homography"` for geometric estimates; never present them as observations. Being inside image bounds does not prove a projected feature is visible. Do not report a homography unless you actually estimated and checked it.
4. If position or identity is unreliable, use `visibility: "uncertain"` with null coordinates, or omit that point. Out-of-frame and occluded points also require null coordinates with the appropriate visibility. Keep every frame record; explicit uncertain/lost/no-panel statuses are valid.
5. Make a SECOND visual pass over each image and check EVERY point reported as observed against the actual feature. Correct misplaced points; verify identities across adjacent frames, especially when zooming, tilting or losing panel edges. Recheck ambiguity instead of copying a prior visibility decision.
6. Validate against `format.json`, then run the local semantic validator when execution is available. Fix failures and rerun. A schema pass checks structure, NOT pixel accuracy. Small flow/homography residuals are not an independent accuracy test.

## Verification evidence inside the returned JSON

For each frame add `quality.visual_review` with `image_viewed_individually`, `second_pass_completed`, `observed_points_checked`, `limitations`, and `checks`. Each check contains `track_id`, the observed `feature`, `result` (`"pass"` or `"uncertain"`), and a brief factual `note`. Include at least three spatially spread observed points when available, or every observed point if fewer than three exist. Explain no-point frames. These sample records do not replace checking all observed points.

Add a top-level `verification` object with `frames_expected`, `frames_viewed_individually`, `frames_second_pass_completed`, `schema_validation`, `semantic_validation`, and `pixel_accuracy`. Record actual tools/commands and results, or `"not_run"` with a reason. If pixel accuracy is not independently measured, say `"not independently measured"`. These extra fields are permitted by the schema.

Provide concise observable evidence, not private reasoning. Never invent inspection, validation, timing or error measurements. Self-reported checks are subject to independent image review. There is no arbitrary minimum thinking time: finish the checks before handing back.

## Local validation and ordered reading

After placing your returned file beside this README:

```bash
python3 read_tracking.py validate . --labels tracking.json --complete
python3 read_tracking.py stream . --labels tracking.json
```

The validator checks frame identity/order, source-image hashes, bounds, visibility and grid IDs. `--complete` rejects still-unlabeled frames. The stream command returns one JSON object per task frame, joining metadata to labels. It never includes example/context images in the task stream.

The reader also accepts a ZIP path and a separate `--labels` path. For local inference, `iter_frames(packet_path, labels_path)` yields `(frame_metadata, original_jpeg_bytes, annotation)` in order. Before labeling, pass the blank template as `labels_path`. Keep state across sections of the same recording rather than resetting merely because the packet filename changes.

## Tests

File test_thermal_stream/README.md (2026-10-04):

# Thermal stream viewer

A browser viewer for calibrated **32 × 24 MLX90640 temperatures** streamed by the [QT Py firmware](../firmware/README.md). A native C reader handles the serial device; the Node.js server parses packets and sends temperature frames to the browser.

## Requirements

- Node.js 20 or later and npm.
- CMake and a C compiler for the hardware serial reader.
- A QT Py running the firmware for live measurements.

The simulator runs without the sensor or native reader.

## Try the simulator

From the repository root:

```bash
cd test_thermal_stream
npm install
npm run simulate
```

Open <http://localhost:3000>. Simulated THM2 packets exercise the JavaScript parser and browser display without hardware.

## Read the sensor

Connect the board over USB, list the serial ports, and start the viewer:

```bash
npm run list-ports
npm start
```

The default device is `/dev/ttyACM0`. `npm start` builds the native reader automatically. To choose another device or HTTP port:

```bash
npm start -- --serial /dev/ttyACM1 --http-port 3001
```

The HTTP port also accepts the `PORT` environment variable. Ensure your user has access to the selected serial device.

## Validation

```bash
npm test
npm run validate
```

The tests cover packet parsing. The validation script feeds a fragmented, noisy simulated stream through the parser. See the [firmware packet specification](../firmware/README.md#usb-packet-format) for field definitions.

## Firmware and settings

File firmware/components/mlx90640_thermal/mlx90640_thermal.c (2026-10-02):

#include "mlx90640_thermal.h"

#include <stddef.h>

#include "MLX90640_API.h"
#include "MLX90640_I2C_Driver.h"
#include "driver/i2c_master.h"
#include "freertos/FreeRTOS.h"
#include "freertos/task.h"

#define MLX90640_ADDRESS 0x33U
#define MLX90640_STATUS_REGISTER 0x8000U
#define MLX90640_CONTROL_REGISTER 0x800DU
#define MLX90640_PIXEL_START_REGISTER 0x0400U
#define MLX90640_AUX_START_REGISTER 0x0700U
#define MLX90640_AUX_WORDS 64U
#define MLX90640_FRAME_WORDS 834U
#define MLX90640_AUX_INVALID 0x7FFFU
#define MLX90640_DATA_READY_MASK 0x0008U
#define MLX90640_SUBPAGE_MASK 0x0001U
#define MLX90640_STATUS_CLEAR_VALUE 0x0030U
#define MLX90640_REFRESH_RATE_MASK 0x0380U
#define MLX90640_REFRESH_RATE_8_HZ (4U << 7U)
#define MLX90640_CHESS_MODE_MASK 0x1000U
#define MLX90640_TRANSACTION_TIMEOUT_MS 100
#define MLX90640_FRAME_TIMEOUT_MS 500U
#define MLX90640_CHESS_MODE 1
#define MLX90640_EMISSIVITY 0.95f
/* Melexis: in open air the reflected temperature is the sensor ambient minus 8 degrees C. */
#define MLX90640_TA_SHIFT_C 8.0f

static i2c_master_bus_handle_t sensor_bus;
static i2c_master_dev_handle_t sensor_device;
static uint8_t transfer_buffer[MLX90640_THERMAL_PIXELS * 2U];
static uint16_t eeprom[MLX90640_EEPROM_DUMP_NUM];
static paramsMLX90640 calibration;
/* Melexis frame layout: 768 pixel words, 64 aux words, control register, subpage. */
static uint16_t frame_words[MLX90640_FRAME_WORDS];

static void release_bus(void)
{
    if (sensor_device != NULL) {
        (void)i2c_master_bus_rm_device(sensor_device);
        sensor_device = NULL;
    }
    if (sensor_bus != NULL) {
        (void)i2c_del_master_bus(sensor_bus);
        sensor_bus = NULL;
    }
}

static esp_err_t read_words(uint16_t start_register, uint16_t *words, size_t word_count)
{
    if (word_count > MLX90640_THERMAL_PIXELS) {
        return ESP_ERR_INVALID_SIZE;
    }

    const uint8_t address[2] = {
        (uint8_t)(start_register >> 8U),
        (uint8_t)start_register,
    };
    const size_t byte_count = word_count * 2U;
    esp_err_t error = i2c_master_transmit_receive(
        sensor_device,
        address,
        sizeof(address),
        transfer_buffer,
        byte_count,
        MLX90640_TRANSACTION_TIMEOUT_MS);
    if (error != ESP_OK) {
        return error;
    }

    for (size_t index = 0; index < word_count; ++index) {
        words[index] = ((uint16_t)transfer_buffer[index * 2U] << 8U) |
                       transfer_buffer[index * 2U + 1U];
    }

    return ESP_OK;
}

static esp_err_t write_word(uint16_t target_register, uint16_t value)
{
    const uint8_t transaction[4] = {
        (uint8_t)(target_register >> 8U),
        (uint8_t)target_register,
        (uint8_t)(value >> 8U),
        (uint8_t)value,
    };

    return i2c_master_transmit(
        sensor_device,
        transaction,
        sizeof(transaction),
        MLX90640_TRANSACTION_TIMEOUT_MS);
}

/* I2C callbacks required by the Melexis library (MLX90640_I2C_Driver.h). */
void MLX90640_I2CInit(void)
{
}

void MLX90640_I2CFreqSet(int freq)
{
    (void)freq;
}

int MLX90640_I2CGeneralReset(void)
{
    return mlx90640_thermal_reset_bus() == ESP_OK ? 0 : -1;
}

int MLX90640_I2CRead(uint8_t slaveAddr, uint16_t startAddress, uint16_t nMemAddressRead, uint16_t *data)
{
    (void)slaveAddr;
    while (nMemAddressRead > 0U) {
        const uint16_t count = nMemAddressRead > MLX90640_THERMAL_PIXELS
            ? (uint16_t)MLX90640_THERMAL_PIXELS
            : nMemAddressRead;
        if (read_words(startAddress, data, count) != ESP_OK) {
            return -1;
        }
        startAddress += count;
        data += count;
        nMemAddressRead -= count;
    }
    return 0;
}

int MLX90640_I2CWrite(uint8_t slaveAddr, uint16_t writeAddress, uint16_t data)
{
    (void)slaveAddr;
    return write_word(writeAddress, data) == ESP_OK ? 0 : -1;
}

esp_err_t mlx90640_thermal_init(int sda_gpio, int scl_gpio, uint32_t bus_hz)
{
    if (sensor_device != NULL) {
        return ESP_ERR_INVALID_STATE;
    }

    const i2c_master_bus_config_t bus_config = {
        .i2c_port = -1,
        .sda_io_num = sda_gpio,
        .scl_io_num = scl_gpio,
        .clk_source = I2C_CLK_SRC_DEFAULT,
        .glitch_ignore_cnt = 7U,
        .flags.enable_internal_pullup = true,
    };
    esp_err_t error = i2c_new_master_bus(&bus_config, &sensor_bus);
    if (error != ESP_OK) {
        return error;
    }

    error = i2c_master_probe(sensor_bus, MLX90640_ADDRESS, MLX90640_TRANSACTION_TIMEOUT_MS);
    if (error != ESP_OK) {
        release_bus();
        return error;
    }

    const i2c_device_config_t device_config = {
        .dev_addr_length = I2C_ADDR_BIT_LEN_7,
        .device_address = MLX90640_ADDRESS,
        .scl_speed_hz = bus_hz,
        .scl_wait_us = 0U,
    };
    error = i2c_master_bus_add_device(sensor_bus, &device_config, &sensor_device);
    if (error != ESP_OK) {
        release_bus();
        return error;
    }

    if (MLX90640_DumpEE(MLX90640_ADDRESS, eeprom) != 0) {
        release_bus();
        return ESP_FAIL;
    }
    /* Bad- and outlier-pixel warnings are fine (they are corrected per frame); only a
     * corrupt EEPROM is fatal. */
    if (MLX90640_ExtractParameters(eeprom, &calibration) == -MLX90640_EEPROM_DATA_ERROR) {
        release_bus();
        return ESP_ERR_INVALID_RESPONSE;
    }

    uint16_t control_register;
    error = read_words(MLX90640_CONTROL_REGISTER, &control_register, 1U);
    if (error != ESP_OK) {
        release_bus();
        return error;
    }

    control_register &= (uint16_t)~MLX90640_REFRESH_RATE_MASK;
    control_register |= MLX90640_REFRESH_RATE_8_HZ | MLX90640_CHESS_MODE_MASK;
    error = write_word(MLX90640_CONTROL_REGISTER, control_register);
    if (error != ESP_OK) {
        release_bus();
    }
    return error;
}
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

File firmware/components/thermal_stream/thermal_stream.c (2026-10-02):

#include "thermal_stream.h"

#include <math.h>
#include <stddef.h>
#include <stdint.h>

#include "board_config.h"
#include "driver/usb_serial_jtag.h"
#include "driver/usb_serial_jtag_vfs.h"
#include "esp_log.h"
#include "esp_timer.h"
#include "freertos/FreeRTOS.h"
#include "freertos/task.h"
#include "mlx90640_thermal.h"

#define THERMAL_I2C_HZ 900000U
#define STREAM_VERSION 2U
#define STREAM_HEADER_BYTES 28U
/* Payload: 768 pixel temperatures then the ambient temperature, int16 centi-degrees C. */
#define STREAM_PAYLOAD_WORDS (MLX90640_THERMAL_PIXELS + 1U)
#define STREAM_PAYLOAD_BYTES (STREAM_PAYLOAD_WORDS * 2U)
#define STREAM_PACKET_BYTES (STREAM_HEADER_BYTES + STREAM_PAYLOAD_BYTES)
#define STREAM_TASK_STACK_BYTES 8192U
#define STREAM_TASK_PRIORITY 5U
#define STREAM_MAX_CONSECUTIVE_ERRORS 5U
/* Chess mode refreshes half the pixels per subpage: wait for both before sending. */
#define STREAM_WARMUP_SUBPAGES 2U

static const char *TAG = "thermal_stream";
static mlx90640_thermal_frame_t thermal_frame;
static uint8_t packet[STREAM_PACKET_BYTES];

static void put_u16_le(uint8_t *destination, uint16_t value)
{
    destination[0] = (uint8_t)value;
    destination[1] = (uint8_t)(value >> 8U);
}

static void put_u32_le(uint8_t *destination, uint32_t value)
{
    for (size_t byte = 0; byte < 4U; ++byte) {
        destination[byte] = (uint8_t)(value >> (byte * 8U));
    }
}

static void put_u64_le(uint8_t *destination, uint64_t value)
{
    for (size_t byte = 0; byte < 8U; ++byte) {
        destination[byte] = (uint8_t)(value >> (byte * 8U));
    }
}

static uint32_t crc32(const uint8_t *data, size_t length)
{
    uint32_t crc = UINT32_MAX;
    for (size_t index = 0; index < length; ++index) {
        crc ^= data[index];
        for (uint8_t bit = 0; bit < 8U; ++bit) {
            const uint32_t mask = (uint32_t)-(int32_t)(crc & 1U);
            crc = (crc >> 1U) ^ (0xEDB88320U & mask);
        }
    }
    return ~crc;
}

static uint16_t centi_celsius(float celsius)
{
    if (isnan(celsius)) {
        return (uint16_t)INT16_MIN;
    }
    const float centi = roundf(celsius * 100.0f);
    const float clamped = fminf(fmaxf(centi, (float)(INT16_MIN + 1)), (float)INT16_MAX);
    return (uint16_t)(int16_t)clamped;
}

static void encode_packet(uint32_t sequence)
{
    packet[0] = 'T';
    packet[1] = 'H';
    packet[2] = 'M';
    packet[3] = '2';
    packet[4] = STREAM_VERSION;
    packet[5] = thermal_frame.subpage;
    put_u16_le(&packet[6], STREAM_HEADER_BYTES);
    put_u32_le(&packet[8], sequence);
    put_u64_le(&packet[12], (uint64_t)esp_timer_get_time());
    put_u16_le(&packet[20], STREAM_PAYLOAD_WORDS);
    packet[22] = MLX90640_THERMAL_WIDTH;
    packet[23] = MLX90640_THERMAL_HEIGHT;

    for (size_t index = 0; index < MLX90640_THERMAL_PIXELS; ++index) {
        put_u16_le(
            &packet[STREAM_HEADER_BYTES + index * 2U],
            centi_celsius(thermal_frame.pixels_c[index]));
    }
    put_u16_le(
        &packet[STREAM_HEADER_BYTES + MLX90640_THERMAL_PIXELS * 2U],
        centi_celsius(thermal_frame.ambient_c));

    put_u32_le(
        &packet[24],
        crc32(&packet[STREAM_HEADER_BYTES], STREAM_PAYLOAD_BYTES));
}

static void send_packet(void)
{
    size_t sent = 0U;
    while (sent < sizeof(packet)) {
        const int written = usb_serial_jtag_write_bytes(
            &packet[sent],
            sizeof(packet) - sent,
            portMAX_DELAY);
        if (written > 0) {
            sent += (size_t)written;
        }
    }
}

static void stream_task(void *context)
{
    (void)context;

    esp_err_t error;
    do {
        error = mlx90640_thermal_init(
            BOARD_STEMMA_SDA_GPIO,
            BOARD_STEMMA_SCL_GPIO,
            THERMAL_I2C_HZ);
        if (error != ESP_OK) {
            ESP_LOGE(TAG, "MLX90640 init failed: %s", esp_err_to_name(error));
            vTaskDelay(pdMS_TO_TICKS(1000U));
        }
    } while (error != ESP_OK);

    usb_serial_jtag_driver_config_t serial_config = USB_SERIAL_JTAG_DRIVER_CONFIG_DEFAULT();
    serial_config.tx_buffer_size = 8192U;
    ESP_ERROR_CHECK(usb_serial_jtag_driver_install(&serial_config));
    usb_serial_jtag_vfs_use_driver();
    usb_serial_jtag_vfs_set_tx_line_endings(ESP_LINE_ENDINGS_LF);

    ESP_LOGI(TAG, "MLX90640 streaming calibrated temperatures, 8 subpages/s");
    vTaskDelay(pdMS_TO_TICKS(50U));
    esp_log_level_set("*", ESP_LOG_NONE);

    uint32_t sequence = 0U;
    uint32_t consecutive_errors = 0U;
    uint32_t subpages_read = 0U;
    for (;;) {
        error = mlx90640_thermal_read(&thermal_frame);
        if (error != ESP_OK) {
            if (++consecutive_errors >= STREAM_MAX_CONSECUTIVE_ERRORS) {
                (void)mlx90640_thermal_reset_bus();
                consecutive_errors = 0U;
            }
            vTaskDelay(pdMS_TO_TICKS(1U));
            continue;
        }

        consecutive_errors = 0U;
        if (subpages_read < STREAM_WARMUP_SUBPAGES) {
            ++subpages_read;
            continue;
        }
        encode_packet(sequence++);
        send_packet();
    }
}

esp_err_t thermal_stream_start(void)
{
    const BaseType_t created = xTaskCreate(
        stream_task,
        "thermal_stream",
        STREAM_TASK_STACK_BYTES,
        NULL,
        STREAM_TASK_PRIORITY,
        NULL);

    return created == pdPASS ? ESP_OK : ESP_ERR_NO_MEM;
}

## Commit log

2026-10-02 added docs for firmware devices
2026-10-02 added thermal camera serial streaming
2026-10-02 added camera streaming to build ML dataset
2026-10-02 dataset builder for ML pipeline using the android apps camera. Reads hand movement
2026-10-02 replaced node native serial driver with C version to avoid throttling device throughput
2026-10-02 added thermal calibration to the device
2026-10-02 fixed calibration bugs
2026-10-02 fixed small tilt issues in calibration
2026-10-03 add 3D housing models (CAD, STL, gcode, simulation studies)
    [4469 MLX90640 Stemma (1).SLDASM, 4469 MLX90640 Stemma (1).step, 4469 MLX90640 Stemma.step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]
2026-10-03 gitignore simulation results, add housing study results to README
2026-10-03 expand housing study writeup in README
2026-10-03 calibration made more accurate with more direct measurements
